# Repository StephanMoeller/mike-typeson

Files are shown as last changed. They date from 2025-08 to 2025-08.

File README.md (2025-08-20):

# Mike Typeson
He is not pretty, but he gets the job done.

This is my first keyboard that has a home grown pcb. It is wired as a unibody even though the electronics are in 3 pieces. I made it because I needed a simple keyboard that did not require i2c, to test out my custom firmware found here: https://github.com/StephanMoeller/zigmkay

b1fb5cf4-bc29-4709-b4f0-31c480e18a1a
442bb95f-c870-497b-adc6-8a3ebe000fcf
37202127-8493-4c16-88e7-75163808c472
90c4d13e-cd23-4fc0-9a72-0eb54dd3bda3
b421c804-b28c-44dd-b487-9335477f5a72

An stl can be found directly in this repo (mike-typeson.stl)

To build this, the following things are needed:

- 3d printed case
- PCB
- THT diodes (30 pieces)
- Khailh mx sockets (30 pieces)
- A xiao rp2040 microcontroller
- 16 jumper wires with female dupont in both ends

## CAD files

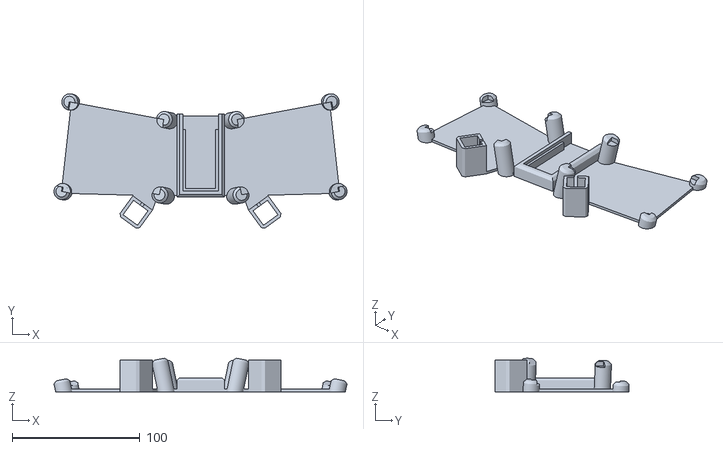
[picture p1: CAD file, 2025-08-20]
mike-typeson.stl
229.4 x 105.3 x 26.3

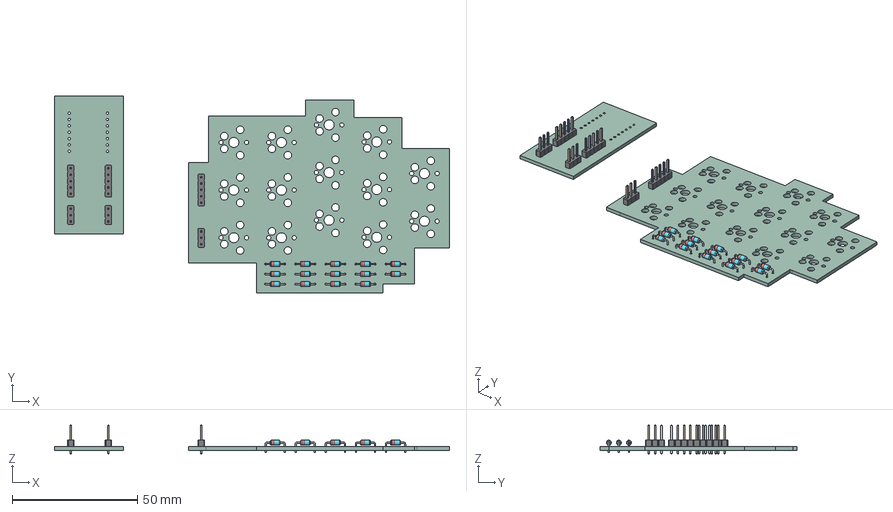
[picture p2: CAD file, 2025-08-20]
mike_typeson_kicad_project/singlepcbino/singlepcbino.step
157.5 x 78.5 x 11.5 mm
Diode_DO-35 x 14
PinHeader_1x05_P2.54mm_Vertical x 3
PinHeader_1x03_P2.54mm_Vertical x 3
singlepcbino_PCB_1
singlepcbino_PCB_2

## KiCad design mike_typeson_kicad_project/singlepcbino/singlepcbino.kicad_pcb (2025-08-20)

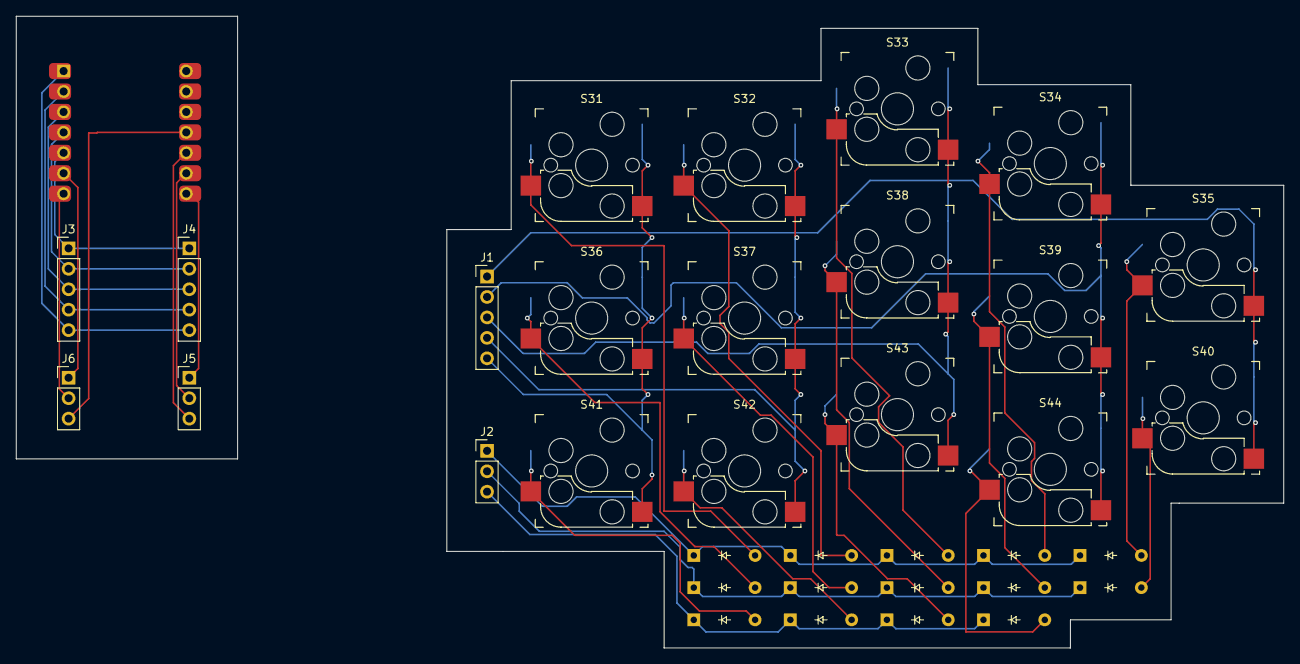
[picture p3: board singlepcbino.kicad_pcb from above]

Board: 2 copper layers, 104.0 x 77.0 mm, 35 parts (0 on the bottom side), 33 nets.

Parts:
J1, J3, J4: Conn_01x05; PinHeader_1x05_P2.54mm_Vertical
J2, J5, J6: Conn_01x03; PinHeader_1x03_P2.54mm_Vertical
S31: a40; Kailh_socket_MX_reversible
S32: a30; Kailh_socket_MX_reversible
S33: a20; Kailh_socket_MX_reversible
S34: a10; Kailh_socket_MX_reversible
S35: a00; Kailh_socket_MX_reversible
S36: a41; Kailh_socket_MX_reversible
S37: a31; Kailh_socket_MX_reversible
S38: a21; Kailh_socket_MX_reversible
S39: a11; Kailh_socket_MX_reversible
S40: a01; Kailh_socket_MX_reversible
S41: a42; Kailh_socket_MX_reversible
S42: a32; Kailh_socket_MX_reversible
S43: a22; Kailh_socket_MX_reversible
S44: a12; Kailh_socket_MX_reversible
U1: MCU_Seeed_XIAO_RP2040; Seeed_XIAO_RP2040
a00, a01, a10, a11, a12, a20, a21, a22, a30, a31, a32, a40, a41, a42: Diode; Diode_DO-35

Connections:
/col0: J1.5, S31.1, S36.1, S41.1
/col1: J1.4, S32.1, S37.1, S42.1
/col2: J1.3, S33.1, S38.1, S43.1
/col3: J1.2, S34.1, S39.1, S44.1
/col4: J1.1, S35.1, S40.1
/row0: J2.1, a00.1 (K), a10.1 (K), a20.1 (K), a30.1 (K), a40.1 (K)
/row1: J2.2, a01.1 (K), a11.1 (K), a21.1 (K), a31.1 (K), a41.1 (K)
unnamed: J2.3, a12.1 (K), a22.1 (K), a32.1 (K), a42.1 (K)
unnamed: J3.1, J4.1, U1.5 (PA8_A4_D4_SDA)
unnamed: J3.2, J4.2, U1.4 (PA11_A3_D3)
unnamed: J3.3, J4.3, U1.3 (PA10_A2_D2)
unnamed: J3.4, J4.4, U1.2 (PA4_A1_D1)
unnamed: J3.5, J4.5, U1.1 (PA02_A0_D0)
unnamed: J5.1, U1.8 (PB09_A7_D7_RX)
unnamed: J5.2, U1.9 (PA7_A8_D8_SCK)
unnamed: J5.3, U1.10 (PA5_A9_D9_MISO)
unnamed: J6.1, U1.6 (PA9_A5_D5_SCL)
unnamed: J6.2, U1.7 (PB08_A6_D6_TX)
unnamed: J6.3, U1.11 (PA6_A10_D10_MOSI)
unnamed: S35.2, a00.2 (A)
unnamed: S40.2, a01.2 (A)
unnamed: S34.2, a10.2 (A)
unnamed: S39.2, a11.2 (A)
unnamed: S44.2, a12.2 (A)
unnamed: S33.2, a20.2 (A)
unnamed: S38.2, a21.2 (A)
unnamed: S43.2, a22.2 (A)
unnamed: S32.2, a30.2 (A)
unnamed: S37.2, a31.2 (A)
unnamed: S42.2, a32.2 (A)
unnamed: S31.2, a40.2 (A)
unnamed: S36.2, a41.2 (A)
unnamed: S41.2, a42.2 (A)
